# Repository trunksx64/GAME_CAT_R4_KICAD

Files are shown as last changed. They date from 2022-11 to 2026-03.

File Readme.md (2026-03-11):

# Game//Cat ::: Revisión R4 :: Versión 4.2.2

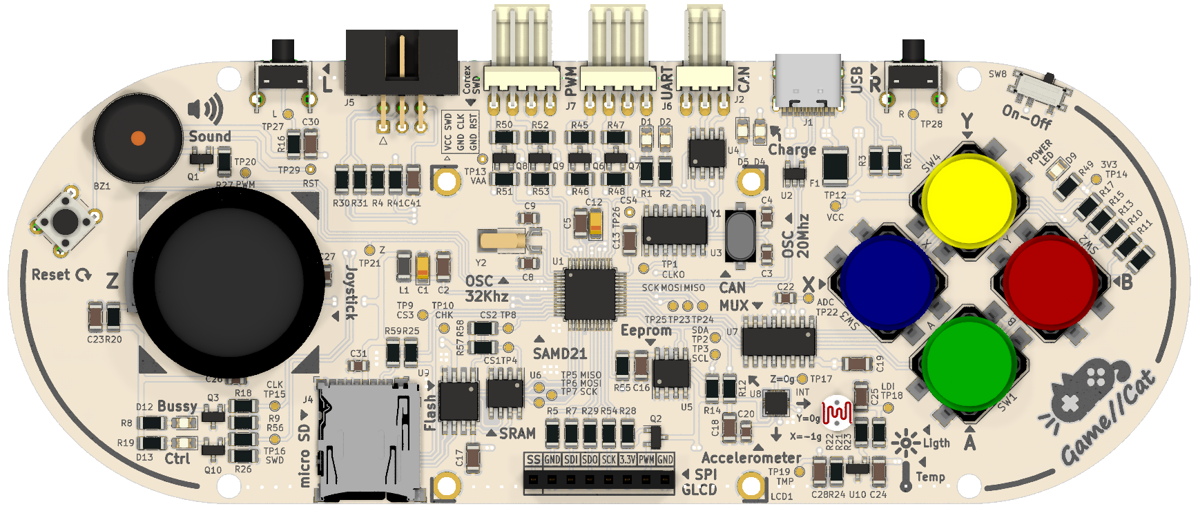
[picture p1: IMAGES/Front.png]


## Razón e Inspiración

El Game//Cat R4 es la evolución del microcontrolador de 16Bits a 32Bits, mas específicamente del PIC24H al ATSAMD21 como núcleo de control, al igual que su antecesor la idea de esta tarjeta y/ó control de desarrollo es usar dispositivos específicos para el aprendizaje, bricolaje y Hobby para proyectos abiertos o de diseño cerrado, el Hardware el Libre con la posibilidad de adaptarlo, modificarlo, cambiarlo a necesidad, claramente respetando al original. El ATSAMD21 es un microcontrolador Originalmente diseñado por ATMEL que utiliza un Nucleo ARM 0M+ dando la ventaja de ser un microcontrolador fácil de usar con Módulos flexibles y robustos, con documentación abundante tanto por lo Comunidad de ARDUINO y la empresa Microchip en este momento. Se diseñó empleando de forma similar la apariencia del Game//Cat R3, agregando mejoras y eliminando errores del anterior, por lo cual es 100% compatible a nivel de diseño.

El ATSAMD21 es compatible en este momento con Microchip Studio (Atmel Studio) y MPLABX V5.0, tanto con GCC y XC32, para programarlo se puede usar ATMEL ICE, MPLAB SNAP, PICKIT4 y El ICD4, Se planea usar el Bootloader original de ARDUINO Zero en un futuro.

Algunos Elementos "Footprints" y "Symbols" están basados en mis librerías, cuáles encontrarán en este mismo Repositorio.

## Características del Hardware

  * Microcontrolador ATSAMD21.
  * Pantalla LCD PCD8544 (Based Nokia GLCD) - SPI.
  * Joystick Análogo de 2 ejes + Botón Digital.
  * 6 Botones Digitales.
  * Accelerometro - MMA8452Q - I2C. 
  * Sensor de Temperatura (LM61).
  * Sensor de Luz (LDR).
  * Memoria Eeprom 24LCXXX - I2C.
  * Memoria Ram 23KXX - SPI.
  * Memoria Flash SST26VF032B - SPI.
  * Ranura Memoria Micro-SD - SPI.
  * Buzzer por PWM.
  * Conexión USB - Nativa por el ATSAM.
  * Conexión CAN-FD - MCP2518FD.
  * 2 LED´s de Actividad.
  * Salidas Para PWM y UART - Con figurables - 3.3V.
  * Conexión SWD Nativa para Debuger.
  * Cargador de Batería Lipo (MCP73831) con Indicador LED.
  * Regulación 3.3V mediante TPS54231.

## Características Específicas

* Para garantizar el control y tensión correspondiente para el uso de BUS CAN, se utiliza el Transeiver MCP2562FD en conjunto del CI MCP2518FD, haciendo compatible el Control con la última version del protocolo CAN.

* Para Potabilidad he agregado un control para la carga de Baterías de tipo Lipo, este gobernado él con el CI MCP73831, el cual intercambia la alimentación proveniente del conector USB y la Batería según el estado de conexión, se puede usar Baterías de 3,7V en adelante hasta un máximo de 6V, se agregó un interruptor para porder desconectar la Batería en modo portable, para evitar su descarga prologanda.

* Para el Manejo del Joystick, Botones, he empleado el CI-74HC4051, que es un Multiplexor Análogo para leer los Valores por el módulo ADC, el cual puede usarse de 10 o 12Bits en conjunto con un canal DMA si fuere necesario.

* La Comunicación por algunos de los Módulos SERCOM disponibles en los conectores Molex, posee un conversor de tensión de 3.3V a 5V de forma bidireccional con transistores Mosfet, con el fin de proteger y poder comunicar el ATSAMD21 con cualquier tipo de dispositivo.

* La Comunicación USB está dedicada por el mismo ATSAMD21, por lo que es necesario programar el Stack propio, este microcontrolador posee una enorme flexibilidad para configurar impactando de forma mínima los recursos. Es posible utilizar el Bootloader del Arduino Zero con algunas modificaciones, aún está en planes de creación, recomiendo emplear el código Generado por AMTEL START, para simplificar las configuraciones tanto de este Módulo como otros Periféricos.

* La Ranura para la Tarjeta Micro-SD, posee conexión Módulo SPI la cual esta compartida con la Memoria Ram 23Kxxx y Memoria Flash SST26VF032B, Además la pantalla posee también una conexión al segundo Módulo SPI, que puede usarse para "colgar" otros dispositivos si no vamos a usar la Pantalla.

* El control del Buzzer se ha dejado por un Pin que puede ser usado tanto por el Modulo PWM o un pin Común, su uso dependerá del Programa o Aplicación.

* Posee una Memoria I2C en conjunto con un Accelerometro, con comunicación directa.

* Los sensores de Luminosidad y Temperatura están conectados directamente a entradas Analógicas del ATSAMD21, no siendo necesario utilizar le MUX 74HC4051.

* La programación se hace por medio de la conexión ICSP o Bootloader por USB, empleando cualquier programador reciente como el ICD4, PICKIT4, SNAP o ATMEL ICE, igual estas salidas pueden usarse como cualquier puerto, teniendo presente que no poseen ninguna protección a tensiones superiores de 3,3V.

* Ya por Último, he dejado dos visualiza-dores, que usan los pines asignados para la Programación del ATSAMD21, controlados por Mosfets para no interferir con el protocolo SWD, su uso está condicionado fuera del Debug.

## Microcontrolador

  * Microcontrolador ATSAMD21 ARM 0M+ de 32Bits.
  * 256KB of flash and 32KB of SRAM.
  * Up to 48MHz operating frequency.
  * Six serial communication modules (SERCOM) configurable as UART/USART, SPI or I2C, three 16-bit timer/counters, 32-bit Real-Time Clock and calendar, 20 PWM channels, one 14-channel 12-bit ADC, one 10-bit DAC.
  * Full Speed USB Device and embedded Host.
  * 1.62V to 3.63V power supply.
  * Internal and external clock options with 48MH Digital Frequency Locked Loop (DFLL48M) and 48MHto 96MHFractional.
  * Two-pin Serial Wire Debug (SWD) programming, test and debugging interface.
  * 38 GPIO pins.
  * 10-bit, 350ksps Digital-to-Analog Converter (DAC).
  * CRC-32 generator.
  * 32-bit Real Time Counter (RTC) with clock/calendar function.
  * Generation of synchronized pulse width modulation (PWM) pattern across port pins.

## Versiones

* 2021 : 4.0.0 : Primera Versión de Diseño.
* 2021 : 4.0.1 : Mirgración completa a Kicad V6, actualización del Libreias y Logos de Diseño.
* 2021 : 4.1.0 : Cambio de Botones Pasantes a SDM.
* 2021 : 4.1.2 : Conectores Moles de tres pines a cuatro pines para Alimentación externar de dispositivos.
* 2021 : 4.1.3 : Correción y cambio de puerto de Programación SWD RJ11 a Header 2x3, similar al AVR SPI.
* 2021 : 4.1.4 : Cambio de Resistencias del conversor de nivel 5V-3.3V de 1K a 10K.
* 2022 : 4.1.5 : Se agregó Interruptor de Encendio por Batería con control Mosfet.
* 2024 : 4.1.6 : Se Elimia Resistencia de Pull para la Linea SWCLK.
* 2024 : 4.1.8 : Se Elimia Diodo del Control de Batería del control Mosfet
* 2025 : 4.2.2 : Se Corrige Mosfet de los LEDs de Estado y Conexion del BUS I2C.

## Créditos

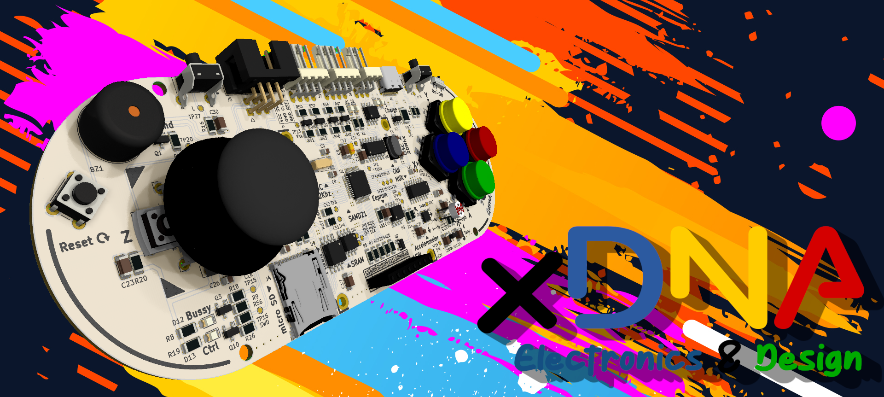
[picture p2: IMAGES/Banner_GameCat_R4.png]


xDNA Electronics & Desing es una Micro-empresa Personal, que se dedica y encarga de elaborar proyectos de Control y Automatización por pedido, su idea es colaborar y ayudar a quines a si lo requieran, el proyecto se hizo principalmente como Hobby el cual gracias a terceros se pudo implementar y hacer su creación, por lo cual se da la libertad de usarlo para experimentar sin hacer uso comercial del mismo.

## Licencia

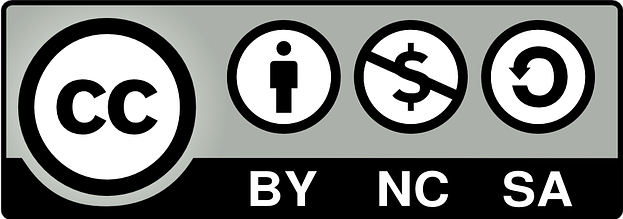
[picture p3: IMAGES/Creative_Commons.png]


Licensed under Attribution-NonCommercial-ShareAlike 4.0 International (CC BY-NC-SA 4.0)

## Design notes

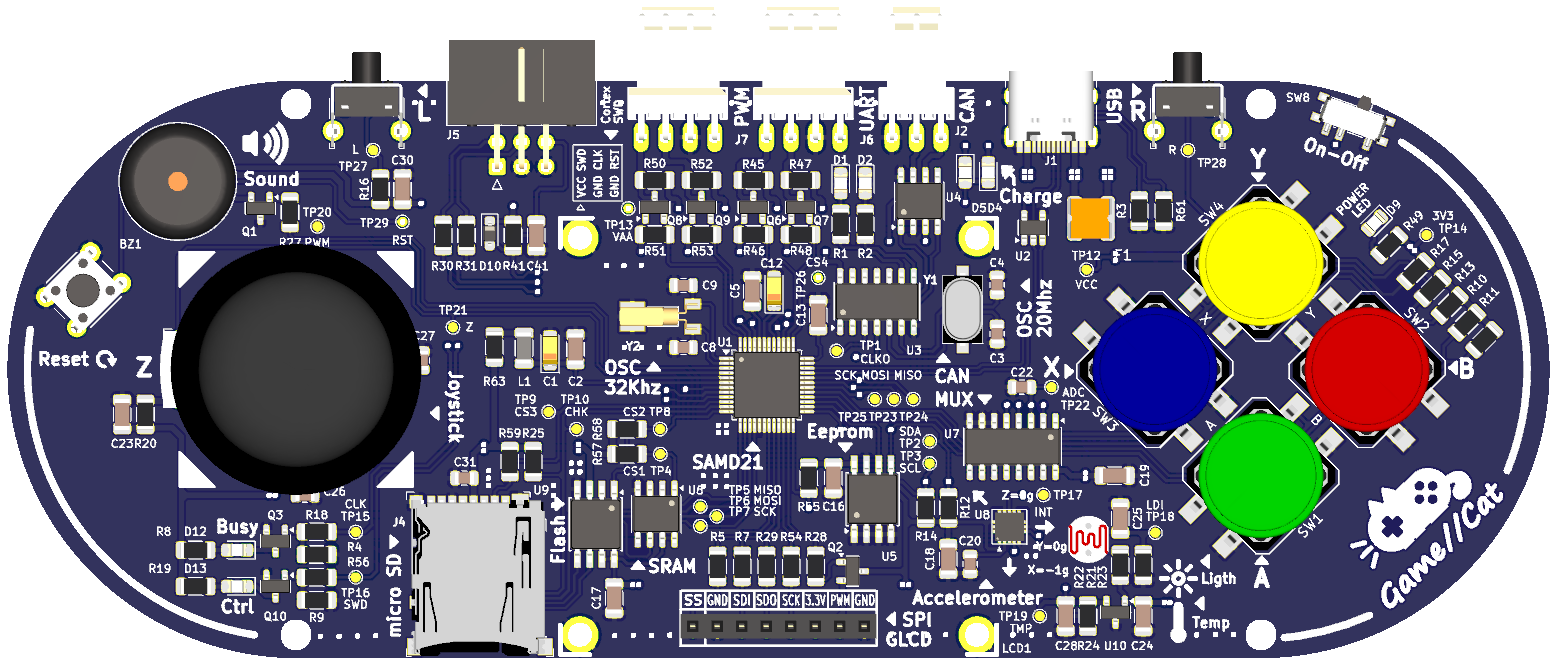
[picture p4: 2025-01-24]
Game_Cat_R4.png

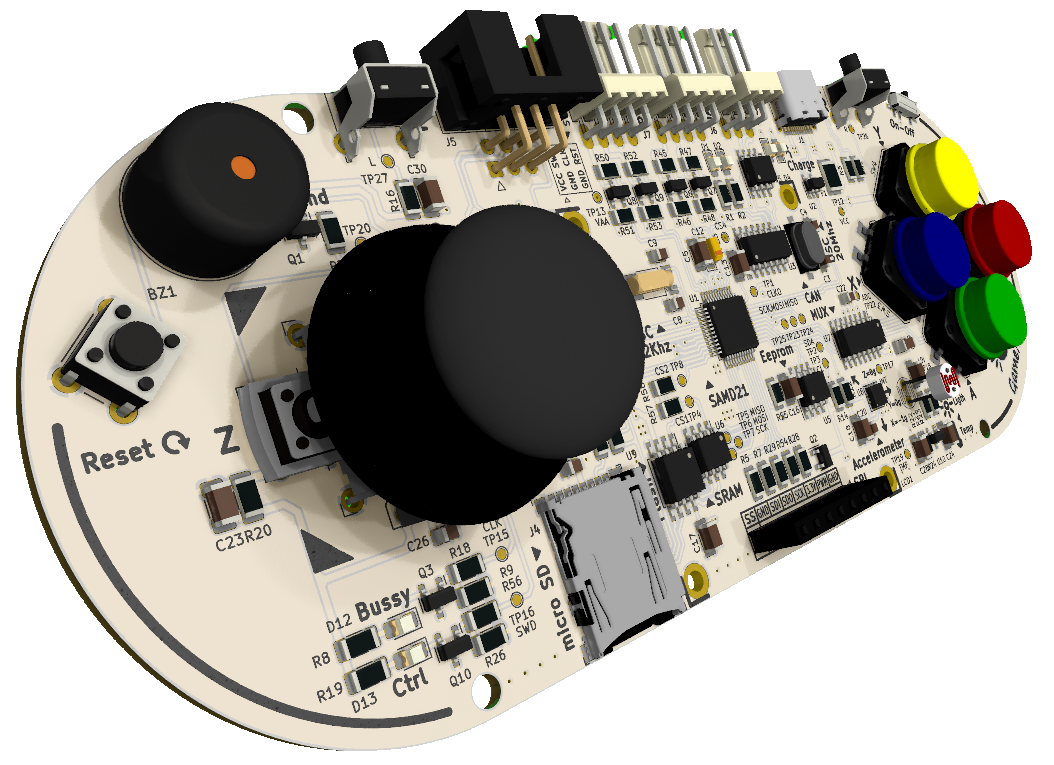
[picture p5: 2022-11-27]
IMAGES/Persp.png

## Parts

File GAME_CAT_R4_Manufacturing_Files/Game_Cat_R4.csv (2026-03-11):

# | Qty | Reference | Footprint | Value | Digikey | Datasheet
1 | 1 | BT1 | x_Connector_JST:S2B_PH_SM4_TB | 3V7 |  | ~
2 | 1 | BZ1 | Buzzer_Beeper:Buzzer_12x9.5RM7.6 | Buzzer |  | ~
3 | 1 | C1 | Capacitor_Tantalum_SMD:CP_EIA-3216-18_Kemet-A | 4.7uF | TAJA475K016RNJ | https://datasheets.kyocera-avx.com/TAJ.pdf
4 | 1 | C2 | Capacitor_SMD:C_1206_3216Metric | 100nF | C3216X7R2E104K160AE | https://product.tdk.com/system/files/dam/doc/product/capacitor/ceramic/mlcc/catalog/mlcc_commercial_soft_en.pdf
5 | 1 | C38 | Capacitor_SMD:C_1206_3216Metric | 15pF |  | ~
6 | 1 | C39 | Capacitor_Tantalum_SMD:CP_EIA-3216-18_Kemet-A | 4.7uF |  | ~
7 | 6 | C10,C23,C25,C28,C30,C41 | Capacitor_SMD:C_1206_3216Metric | 10nF |  | ~
8 | 3 | C12,C36,C45 | Capacitor_Tantalum_SMD:CP_EIA-3216-18_Kemet-A | 1uF |  | ~
9 | 4 | C20,C26,C27,C31 | Capacitor_SMD:C_0805_2012Metric | 10pF |  | ~
10 | 3 | C3,C4,C22 | Capacitor_SMD:C_0805_2012Metric | 22pF |  | ~
11 | 2 | C37,C42 | Capacitor_SMD:C_0805_2012Metric,Capacitor_SMD:C_1206_3216Metric | 47pF |  | ~
12 | 10 | C5,C11,C13,C16,C17,C18,C19,C24,C33,C40 | Capacitor_SMD:C_1206_3216Metric | 100nF |  | ~
13 | 2 | C8,C9 | Capacitor_SMD:C_0805_2012Metric | 22pF | C0805C220J5GAC7800 | https://content.kemet.com/datasheets/KEM_C1003_C0G_SMD.pdf
14 | 1 | D3 | Package_TO_SOT_SMD:SOT-23 | NUP2105L |  | http://www.onsemi.com/pub_link/Collateral/NUP2105L-D.PDF
15 | 1 | D6 | Diode_SMD:D_SOD-123 | 1N5819HW |  | ~
16 | 7 | D1,D2,D4,D5,D9,D12,D13 | LED_SMD:LED_0805_2012Metric,LED_SMD:LED_0805_2012Metric_Castellated | LED |  | ~
17 | 2 | D8,D10 | Diode_SMD:D_SOD-323_HandSoldering | BAT60J |  | ~
18 | 1 | F1 | x_Fuses:MF_SMDF200 | 500mA |  | ~
19 | 1 | J1 | x_Connector_USB:USB_C_HRO_TYPE-C-31-M-12 | USB_C |  | https://www.usb.org/sites/default/files/documents/usb_type-c.zip
20 | 1 | J2 | x_Connector_Molex:MOLEX_KK_1x03_P2.54mm_HORIZONTAL | CAN |  | ~
21 | 1 | J3 | x_Joystick:JOYSTICK_TUMB | Joystick | 09032 | https://mm.digikey.com/Volume0/opasdata/d220001/medias/docus/2339/COM-09032_Web.pdf
22 | 1 | J5 | Connector_IDC:IDC-Header_2x03_P2.54mm_Horizontal | CORTEX-SWD |  | ~
23 | 1 | J6 | x_Connector_Molex:MOLEX_KK_1x04_P2.54mm_HORIZONTAL | UART |  | ~
24 | 1 | J8 | x_Connector_Card:DM3AT_SF_PEJM5 | DM3AT-SF-PEJM5 | DM3AT-SF-PEJM5 | https://www.hirose.com/product/document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
25 | 2 | J7,TP20 | TestPoint:TestPoint_Pad_D1.0mm,x_Connector_Molex:MOLEX_KK_1x04_P2.54mm_HORIZONTAL | PWM |  | ~
26 | 1 | JP1 | Jumper:SolderJumper-2_P1.3mm_Open_RoundedPad1.0x1.5mm | Jumper CAN |  | ~
27 | 1 | L1 | Inductor_SMD:L_1206_3216Metric | FB321611T | FB321611T-260Y-S | https://calchip.com/wp-content/uploads/2023/03/fb_series.pdf
28 | 1 | L2 | Inductor_SMD:L_1206_3216Metric | BLM18PG471 |  | ~
29 | 1 | L3 | x_Inductor_SMD:L_Murata_82103C | 82103C |  | ~
30 | 1 | LCD1 | x_Display:GLCD_PCD8544_BASE | PCD8544
31 | 1 | Q4 | Package_TO_SOT_SMD:SOT-23 | FDN340P |  | ~
32 | 1 | Q5 | Package_TO_SOT_SMD:SOT-23 | NTR1P02LT1 |  | ~
33 | 2 | Q1,Q2 | Package_TO_SOT_SMD:SOT-23 | 2N2907 |  | ~
34 | 2 | Q3,Q10 | Package_TO_SOT_SMD:SOT-23 | 2N7002 |  | https://www.fairchildsemi.com/datasheets/2N/2N7002.pdf
35 | 4 | Q6,Q7,Q8,Q9 | Package_TO_SOT_SMD:SOT-23 | BS138 |  | ~
36 | 1 | R6 | Resistor_SMD:R_1206_3216Metric | 120R |  | ~
37 | 1 | R22 | x_OptoDevice:PHOTO_CELL_VT900 | R_PHOTO |  | ~
38 | 1 | R23 | Resistor_SMD:R_1206_3216Metric | 100K | RC1206FR-07100KL | https://www.yageo.com/upload/media/product/products/datasheet/rchip/PYu-RC_Group_51_RoHS_L_12.pdf
39 | 1 | R28 | Resistor_SMD:R_1206_3216Metric | 10R | RC1206FR-0710RL | https://www.yageo.com/upload/media/product/products/datasheet/rchip/PYu-RC_Group_51_RoHS_L_12.pdf
40 | 1 | R35 | Resistor_SMD:R_1206_3216Metric | 332R | RC1206FR-07332RL | https://www.yageo.com/upload/media/product/products/datasheet/rchip/PYu-RC_Group_51_RoHS_L_12.pdf
41 | 1 | R36 | Resistor_SMD:R_1206_3216Metric | 68K | RC1206FR-0768KL | https://www.yageo.com/upload/media/product/products/datasheet/rchip/PYu-RC_Group_51_RoHS_L_12.pdf
42 | 1 | R37 | Resistor_SMD:R_1206_3216Metric | 30K | RC1206FR-0730KL | https://www.yageo.com/upload/media/product/products/datasheet/rchip/PYu-RC_Group_51_RoHS_L_12.pdf
43 | 1 | R40 | Resistor_SMD:R_1206_3216Metric | 180 | RC1206JR-07180RL | https://www.yageo.com/upload/media/product/products/datasheet/rchip/PYu-RC_Group_51_RoHS_L_12.pdf
44 | 1 | R43 | Resistor_SMD:R_1206_3216Metric | 3K | RC1206FR-073KL | https://www.yageo.com/upload/media/product/products/datasheet/rchip/PYu-RC_Group_51_RoHS_L_12.pdf
45 | 1 | R55 | Resistor_SMD:R_1206_3216Metric | 4K7 | RC1206FR-074K7L | https://www.yageo.com/upload/media/product/products/datasheet/rchip/PYu-RC_Group_51_RoHS_L_12.pdf
46 | 5 | R1,R2,R8,R19,R27 | Resistor_SMD:R_1206_3216Metric | 2K2 | RC1206FR-072K2L | https://www.yageo.com/upload/media/product/products/datasheet/rchip/PYu-RC_Group_51_RoHS_L_12.pdf
47 | 2 | R18,R56 | Resistor_SMD:R_1206_3216Metric | 100R | RC1206JR-07100RL | https://www.yageo.com/upload/media/product/products/datasheet/rchip/PYu-RC_Group_51_RoHS_L_12.pdf
48 | 2 | R24,R49 | Resistor_SMD:R_1206_3216Metric | 33R | RC1206JR-0733RL | https://www.yageo.com/upload/media/product/products/datasheet/rchip/PYu-RC_Group_51_RoHS_L_12.pdf
49 | 2 | R3,R61 | Resistor_SMD:R_1206_3216Metric | 5K1 | RC1206FR-075K1L | https://www.yageo.com/upload/media/product/products/datasheet/rchip/PYu-RC_Group_51_RoHS_L_12.pdf
50 | 2 | R33,R34 | Resistor_SMD:R_1206_3216Metric | 470R | RC1206JR-07470RL | https://www.yageo.com/upload/media/product/products/datasheet/rchip/PYu-RC_Group_51_RoHS_L_12.pdf
51 | 2 | R38,R44 | Resistor_SMD:R_1206_3216Metric | 2K | RC1206FR-072KL | https://www.yageo.com/upload/media/product/products/datasheet/rchip/PYu-RC_Group_51_RoHS_L_12.pdf
52 | 27 | R4,R9,R10,R11,R12,R13,R14,R15,R16,R17,R20,R21,R25,R39,R41,R42,R45,R46,R47,R48,R50,R51,R52,R53,R57,R58,R59 | Resistor_SMD:R_1206_3216Metric | 10K | RC1206FR-0710KL | https://www.yageo.com/upload/media/product/products/datasheet/rchip/PYu-RC_Group_51_RoHS_L_12.pdf
53 | 11 | R5,R7,R29,R30,R31,R32,R54,R60,R62,R63,R64 | Resistor_SMD:R_1206_3216Metric | 0R | RC1206FR-0710KL | https://www.yageogroup.com/content/datasheet/asset/file/PYU-RC_GROUP_51_ROHS_L
54 | 1 | SW1 | x_Button_Switch_SMD:SWITCH_TACTILE_SPST_PLUNGER_CAP_GREEN_12x12mm_SMD | A
55 | 1 | SW2 | x_Button_Switch_SMD:SWITCH_TACTILE_SPST_PLUNGER_CAP_RED_12x12mm_SMD | B
56 | 1 | SW3 | x_Button_Switch_SMD:SWITCH_TACTILE_SPST_PLUNGER_CAP_BLUE_12x12mm_SMD | X
57 | 1 | SW4 | x_Button_Switch_SMD:SWITCH_TACTILE_SPST_PLUNGER_CAP_YELLOW_12x12mm_SMD | Y
58 | 1 | SW7 | Button_Switch_THT:SW_PUSH_6mm_H5mm | Reset |  | ~
59 | 1 | SW8 | Button_Switch_SMD:SW_SPDT_PCM12 | SW_SPDT |  | ~
60 | 2 | SW5,TP27 | Button_Switch_THT:SW_Tactile_SPST_Angled_PTS645Vx58-2LFS,TestPoint:TestPoint_Pad_D1.0mm | L |  | ~
61 | 2 | SW6,TP28 | Button_Switch_THT:SW_Tactile_SPST_Angled_PTS645Vx58-2LFS,TestPoint:TestPoint_Pad_D1.0mm | R |  | ~
62 | 1 | TP1 | TestPoint:TestPoint_Pad_D1.0mm | CLKO |  | ~
63 | 1 | TP2 | TestPoint:TestPoint_Pad_D1.0mm | SDA |  | ~
64 | 1 | TP3 | TestPoint:TestPoint_Pad_D1.0mm | SCL |  | ~
65 | 1 | TP4 | TestPoint:TestPoint_Pad_D1.0mm | CS1 |  | ~
66 | 1 | TP8 | TestPoint:TestPoint_Pad_D1.0mm | CS2 |  | ~
67 | 1 | TP9 | TestPoint:TestPoint_Pad_D1.0mm | CS3 |  | ~
68 | 1 | TP10 | TestPoint:TestPoint_Pad_D1.0mm | CHK |  | ~
69 | 1 | TP13 | TestPoint:TestPoint_Pad_D1.0mm | VAA |  | ~
70 | 1 | TP14 | TestPoint:TestPoint_Pad_D1.0mm | 3V3 |  | ~
71 | 1 | TP15 | TestPoint:TestPoint_Pad_D1.0mm | CLK |  | ~
72 | 1 | TP16 | TestPoint:TestPoint_Pad_D1.0mm | SWD |  | ~
73 | 1 | TP17 | TestPoint:TestPoint_Pad_D1.0mm | INT |  | ~
74 | 1 | TP18 | TestPoint:TestPoint_Pad_D1.0mm | LDI |  | ~
75 | 1 | TP19 | TestPoint:TestPoint_Pad_D1.0mm | TMP |  | ~
76 | 1 | TP21 | TestPoint:TestPoint_Pad_D1.0mm | Z |  | ~
77 | 1 | TP22 | TestPoint:TestPoint_Pad_D1.0mm | ADC |  | ~
78 | 1 | TP26 | TestPoint:TestPoint_Pad_D1.0mm | CS4 |  | ~
79 | 1 | TP29 | TestPoint:TestPoint_Pad_D1.0mm | RST |  | ~
80 | 2 | TP11,TP12 | TestPoint:TestPoint_Pad_D1.0mm | VCC |  | ~
81 | 2 | TP5,TP24 | TestPoint:TestPoint_Pad_D1.0mm | MISO |  | ~
82 | 2 | TP6,TP23 | TestPoint:TestPoint_Pad_D1.0mm | MOSI |  | ~
83 | 2 | TP7,TP25 | TestPoint:TestPoint_Pad_D1.0mm | SCK |  | ~
84 | 1 | U1 | Package_QFP:TQFP-48_7x7mm_P0.5mm | ATSAMD21G18A | ATSAMD21G18A-AU | https://ww1.microchip.com/downloads/en/DeviceDoc/SAM-D21-DA1-Family-Data-Sheet-DS40001882H.pdf
85 | 1 | U2 | Package_TO_SOT_SMD:SOT-23-5 | TPD2E2U06 |  | http://www.ti.com/lit/ds/symlink/tpd2e2u06.pdf
86 | 1 | U3 | Package_SO:SOIC-14_3.9x8.7mm_P1.27mm | MCP2518FD |  | https://ww1.microchip.com/downloads/en/DeviceDoc/20005688A.pdf
87 | 1 | U5 | Package_SO:SOIC-8_5.3x5.3mm_P1.27mm | 24CSM01 | 24CSM01T-E/ST | https://ww1.microchip.com/downloads/aemDocuments/documents/MPD/ProductDocuments/DataSheets/24CSM01-1-Mbit-3.4MHz-I2C-Serial-EEPROM-DS20006781.pdf
88 | 1 | U6 | Package_SO:SOIC-8_3.9x4.9mm_P1.27mm | 23K256 | 23K256-I/SN | https://ww1.microchip.com/downloads/en/DeviceDoc/22100F.pdf
89 | 1 | U7 | Package_SO:SOIC-16_3.9x9.9mm_P1.27mm | 74HC4051 | CD74HC4051QM96Q1 | http://www.ti.com/lit/ds/symlink/cd74hc4051.pdf
90 | 1 | U8 | x_Package_DFN_QFN:QFN_16_3x3x1mm_P0.5mm | MMA8452Q
91 | 1 | U9 | Package_SO:SOIC-8_5.3x5.3mm_P1.27mm | AT25DF641A | AT25DF641A-SH-B | https://www.renesas.com/us/en/document/dst/at25df641a-datasheet?language=en
92 | 1 | U10 | Package_TO_SOT_SMD:SOT-23 | LM61 |  | http://www.ti.com/lit/ds/symlink/lm35.pdf
93 | 1 | U11 | Package_TO_SOT_SMD:SOT-23-5 | MCP73831
94 | 1 | U12 | Package_SO:SOIC-8_3.9x4.9mm_P1.27mm | TPS54231 |  | http://www.ti.com/lit/ds/symlink/tps54233.pdf
95 | 1 | U13 | Package_SO:SOIC-8_3.9x4.9mm_P1.27mm | TCAN337GDR |  | http://www.ti.com/lit/ds/symlink/tcan337.pdf
96 | 1 | Y1 | x_Crystal:ECS_160_20_3X_TR | 20Mhz |  | ~
97 | 1 | Y2 | x_Crystal:MS1V_T1K_32.768KHZ_7PF_20PPM_TA | Crystal_GND3 | MS1V-T1K-32.768KHZ-9PF-20PPM-TA-QC | https://www.microcrystal.com/fileadmin/Media/Products/32kHz/Datasheet/MS1V-T1K.pdf

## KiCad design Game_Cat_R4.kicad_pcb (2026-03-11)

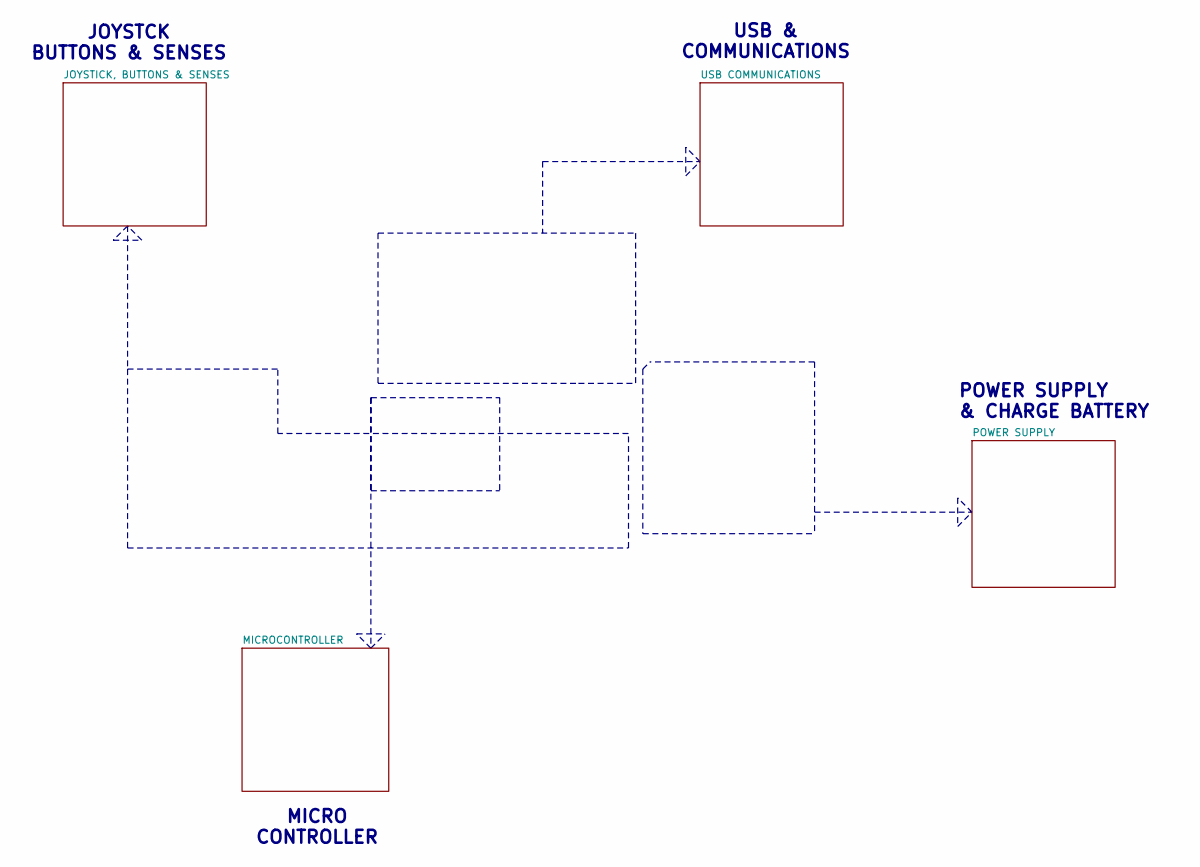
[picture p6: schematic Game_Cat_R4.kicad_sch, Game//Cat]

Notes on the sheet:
POWER SUPPLY & CHARGE BATTERY
MICRO CONTROLLER
USB & COMMUNICATIONS
JOYSTCK BUTTONS & SENSES

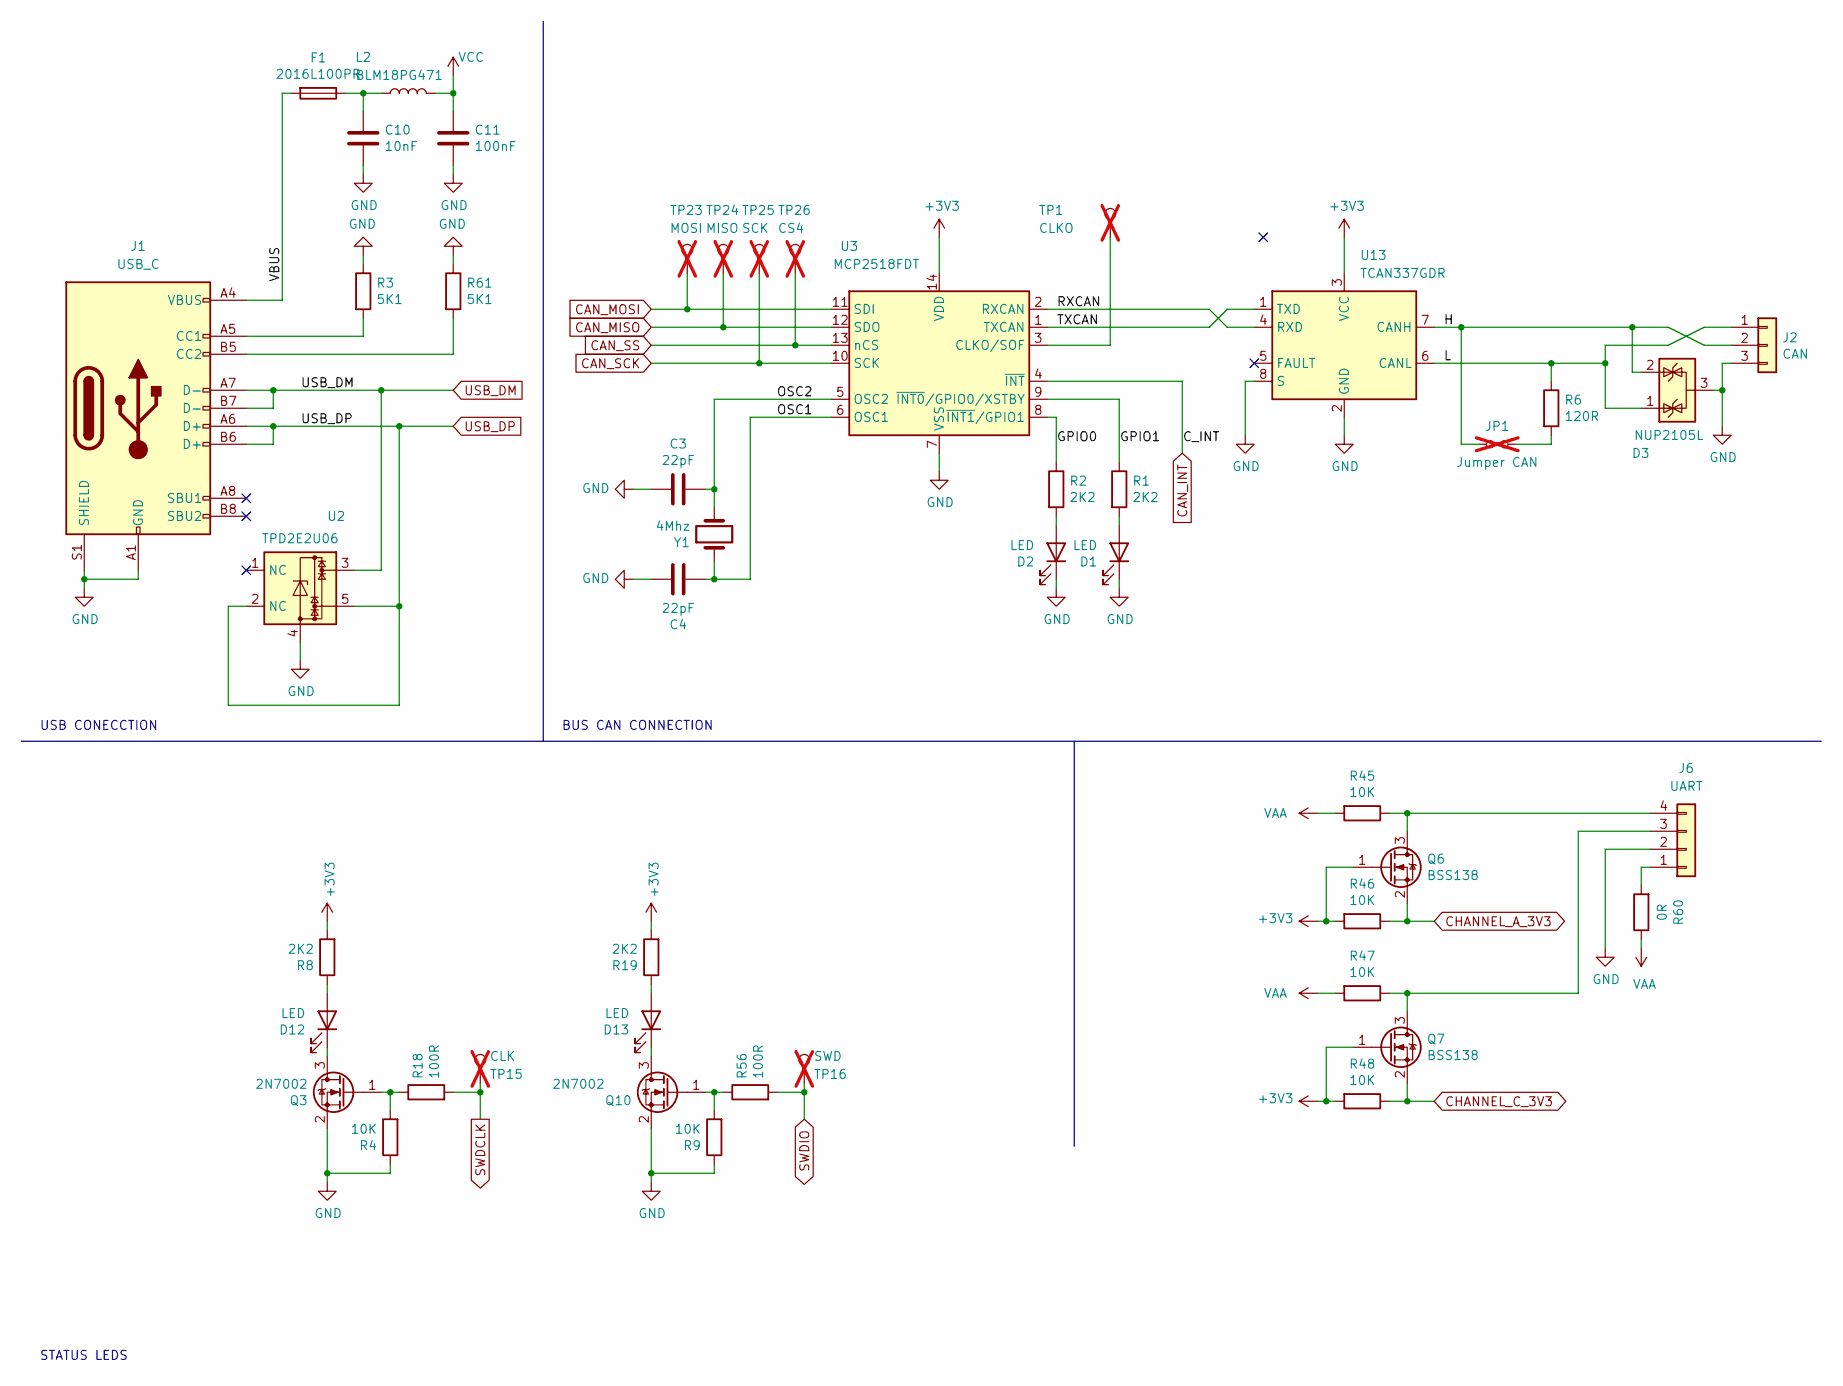
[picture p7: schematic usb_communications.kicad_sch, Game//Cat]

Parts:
C3, C4: 22pF; C_0805_2012Metric; Digikey C0805C220J5GAC7800
C10: 10nF; C_1206_3216Metric; Digikey GRM3195C1H113JA01D
C11: 100nF; C_1206_3216Metric; Digikey C3216X7R2E104K160AE
D1, D2, D12, D13: LED; LED_0805_2012Metric; Digikey LTST-C170GKT
D3: NUP2105L; SOT-23; Digikey NUP2105L
F1: 2016L100PR; MF_SMDF200; Digikey 2016L100PR
J1: USB_C; USB_C_HRO_TYPE-C-31-M-12; Digikey 12402012E212A
J2: CAN; MOLEX_KK_1x03_P2.54mm_HORIZONTAL; Digikey SWR25X-NRTC-S03-RB-BA
J6: UART; MOLEX_KK_1x04_P2.54mm_HORIZONTAL; Digikey SWR25X-NRTC-S04-RB-BA
JP1: Jumper CAN; SolderJumper-2_P1.3mm_Open_RoundedPad1.0x1.5mm; Digikey M20-9990245; not fitted
L2: BLM18PG471; L_1206_3216Metric; Digikey BLM18PG471SZ1D
Q3, Q10: 2N7002; SOT-23; Digikey 2N7002
Q6, Q7: BSS138; SOT-23; Digikey BSS138
R1, R2, R8, R19: 2K2; R_1206_3216Metric; Digikey RC1206FR-072K2L
R3, R61: 5K1; R_1206_3216Metric; Digikey RC1206FR-075K1L
R4, R9, R45, R46, R47, R48: 10K; R_1206_3216Metric; Digikey RC1206FR-0710KL
R6: 120R; R_1206_3216Metric; Digikey RC1206JR-07120RL
R18, R56: 100R; R_1206_3216Metric; Digikey RC1206JR-07100RL
R60: 0R; R_1206_3216Metric; Digikey RC1206FR-0710KL
TP1: CLKO; TestPoint_Pad_D1.0mm; not fitted
TP15: CLK; TestPoint_Pad_D1.0mm; not fitted
TP16: SWD; TestPoint_Pad_D1.0mm; not fitted
TP23: MOSI; TestPoint_Pad_D1.0mm; not fitted
TP24: MISO; TestPoint_Pad_D1.0mm; not fitted
TP25: SCK; TestPoint_Pad_D1.0mm; not fitted
TP26: CS4; TestPoint_Pad_D1.0mm; not fitted
U2: TPD2E2U06; SOT-23-5; Digikey TPD2E2U06DRLR
U3: MCP2518FDT; SOIC-14_3.9x8.7mm_P1.27mm; Digikey MCP2518FDT-H/SL
U13: TCAN337GDR; SOIC-8_3.9x4.9mm_P1.27mm; Digikey TCAN337GDR
Y1: 4Mhz; ECS_160_20_3X_TR; Digikey ECS-200-CDX-0914

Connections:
+3V3: Q6.1 (G), Q7.1 (G), R8.2, R19.2, R46.2, R48.2, U3.14 (VDD), U13.3 (VCC); also elsewhere on the board
/USB COMMUNICATIONS/GPIO0: R2.1, U3.8 (~INT1/GPIO1)
/USB COMMUNICATIONS/GPIO1: R1.1, U3.9 (~INT0/GPIO0/XSTBY)
/USB COMMUNICATIONS/H: D3.2 (K), J2.2, JP1.1, U13.7 (CANH)
/USB COMMUNICATIONS/L: D3.1 (K), J2.1, R6.1, U13.6 (CANL)
/USB COMMUNICATIONS/OSC1: C4.2, U3.6 (OSC1), Y1.1
/USB COMMUNICATIONS/OSC2: C3.2, U3.5 (OSC2), Y1.2
/USB COMMUNICATIONS/RXCAN: U3.2 (RXCAN), U13.4 (RXD)
/USB COMMUNICATIONS/TXCAN: U3.1 (TXCAN), U13.1 (TXD)
/USB COMMUNICATIONS/VBUS: F1.2, J1.A4 (VBUS), J1.A9 (VBUS), J1.B4 (VBUS), J1.B9 (VBUS)
CAN_INT: U3.4 (~INT); also elsewhere on the board
CAN_MISO: TP24.1, U3.12 (SDO); also elsewhere on the board
CAN_MOSI: TP23.1, U3.11 (SDI); also elsewhere on the board
CAN_SCK: TP25.1, U3.10 (SCK); also elsewhere on the board
CAN_SS: TP26.1, U3.13 (nCS); also elsewhere on the board
CHANNEL_A_3V3: Q6.2 (S), R46.1; also elsewhere on the board
CHANNEL_C_3V3: Q7.2 (S), R48.1; also elsewhere on the board
GND: C3.1, C4.1, C10.2, C11.2, D1.1 (K), D2.1 (K), D3.3 (A), J1.A1 (GND), J1.A12 (GND), J1.B1 (GND), J1.B12 (GND), J1.S1 (SHIELD), J2.3, J6.2, Q3.2 (S), Q10.2 (S), R3.1, R4.1, R9.1, R61.1, U2.4, U3.7 (VSS), U13.2 (GND), U13.8 (S); also elsewhere on the board
unnamed: C10.1, F1.1, L2.1
unnamed: D1.2 (A), R1.2
unnamed: D2.2 (A), R2.2
unnamed: D12.2 (A), R8.1
unnamed: D12.1 (K), Q3.3 (D)
unnamed: D13.2 (A), R19.1
unnamed: D13.1 (K), Q10.3 (D)
unnamed: J1.A5 (CC1), R3.2
unnamed: J1.B5 (CC2), R61.2
unnamed: J6.1, R60.2
unnamed: J6.3, Q7.3 (D), R47.1
unnamed: J6.4, Q6.3 (D), R45.1
unnamed: JP1.2, R6.2
unnamed: Q3.1 (G), R4.2, R18.1
unnamed: Q10.1 (G), R9.2, R56.1
unnamed: TP1.1, U3.3 (CLKO/SOF)
SWDCLK: R18.2, TP15.1; also elsewhere on the board
SWDIO: R56.2, TP16.1; also elsewhere on the board
USB_DM: J1.A7 (D-), J1.B7 (D-), U2.3; also elsewhere on the board
USB_DP: J1.A6 (D+), J1.B6 (D+), U2.2 (NC), U2.5; also elsewhere on the board
VAA: R45.2, R47.2, R60.1; also elsewhere on the board
VCC: C11.1, L2.2; also elsewhere on the board

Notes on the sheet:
BUS CAN CONNECTION
STATUS LEDS
USB CONECCTION

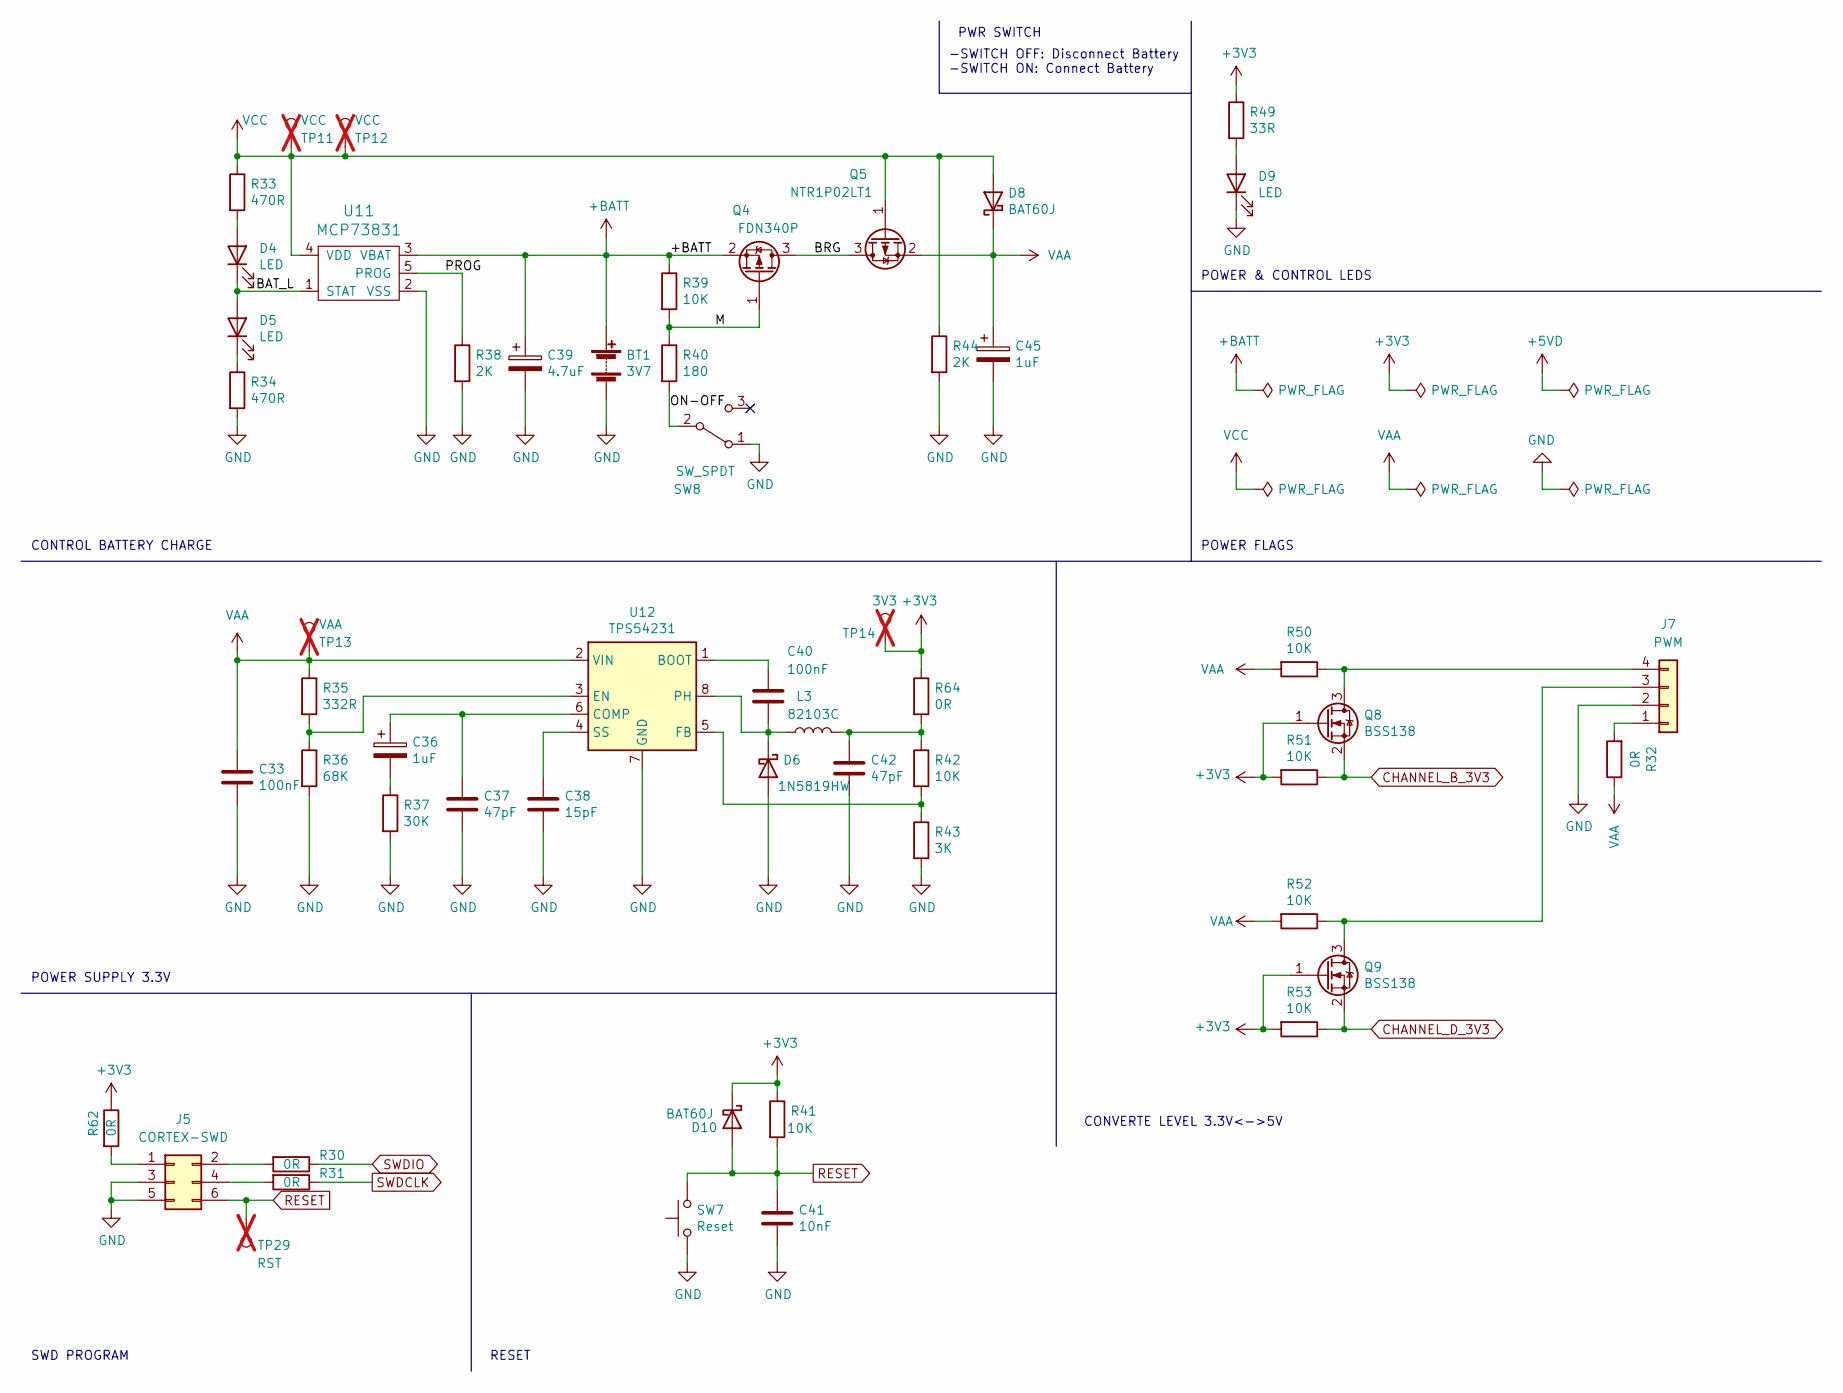
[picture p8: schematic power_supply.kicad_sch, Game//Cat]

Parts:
BT1: 3V7; S2B_PH_SM4_TB; Digikey S2B-PH-SM4-TB
C33, C40: 100nF; C_1206_3216Metric; Digikey C3216X7R2E104K160AE
C36, C45: 1uF; CP_EIA-3216-18_Kemet-A; Digikey TAJA105K016RNJ
C37: 47pF; C_0805_2012Metric; Digikey GRM21A5C2E470JW01D
C38: 15pF; C_1206_3216Metric; Digikey GCM31A5C3A150FX01D
C39: 4.7uF; CP_EIA-3216-18_Kemet-A; Digikey TAJA475K016RNJ
C41: 10nF; C_1206_3216Metric; Digikey GRM3195C1H113JA01D
C42: 47pF; C_1206_3216Metric; Digikey GCM31A5C3A470FX01D
D4, D5, D9: LED; LED_0805_2012Metric; Digikey LTST-C170GKT
D6: 1N5819HW; D_SOD-123; Digikey 1N5819HWQ-7-F
D8, D10: BAT60J; D_SOD-323_HandSoldering; Digikey BAT60JFILM
J5: CORTEX-SWD; IDC-Header_2x03_P2.54mm_Horizontal; Digikey 61200621721
J7: PWM; MOLEX_KK_1x04_P2.54mm_HORIZONTAL; Digikey SWR25X-NRTC-S04-RB-BA
L3: 82103C; L_Murata_82103C; Digikey 82103C
Q4: FDN340P; SOT-23; Digikey FDN340P
Q5: NTR1P02LT1; SOT-23; Digikey NTR1P02LT1G
Q8, Q9: BSS138; SOT-23; Digikey BSS138
R30, R31, R32, R62, R64: 0R; R_1206_3216Metric; Digikey RC1206FR-0710KL
R33, R34: 470R; R_1206_3216Metric; Digikey RC1206JR-07470RL
R35: 332R; R_1206_3216Metric; Digikey RC1206FR-07332RL
R36: 68K; R_1206_3216Metric; Digikey RC1206FR-0768KL
R37: 30K; R_1206_3216Metric; Digikey RC1206FR-0730KL
R38, R44: 2K; R_1206_3216Metric; Digikey RC1206FR-072KL
R39, R41, R42, R50, R51, R52, R53: 10K; R_1206_3216Metric; Digikey RC1206FR-0710KL
R40: 180; R_1206_3216Metric; Digikey RC1206JR-07180RL
R43: 3K; R_1206_3216Metric; Digikey RC1206FR-073KL
R49: 33R; R_1206_3216Metric; Digikey RC1206JR-0733RL
SW7: Reset; SW_PUSH_6mm_H5mm; Digikey PTS645SK50SMTR92 LFS
SW8: SW_SPDT; SW_SPDT_PCM12; Digikey PCM12SMTR
TP11, TP12: VCC; TestPoint_Pad_D1.0mm; not fitted
TP13: VAA; TestPoint_Pad_D1.0mm; not fitted
TP14: 3V3; TestPoint_Pad_D1.0mm; not fitted
TP29: RST; TestPoint_Pad_D1.0mm; not fitted
U11: MCP73831; SOT-23-5; Digikey MCP73831T-5ACI/OT
U12: TPS54231; SOIC-8_3.9x4.9mm_P1.27mm; Digikey TPS54231D

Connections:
+3V3: D10.1 (K), Q8.1 (G), Q9.1 (G), R41.1, R49.1, R51.2, R53.2, R62.1, R64.1, TP14.1; also elsewhere on the board
+BATT: BT1.1 (+), C39.1, Q4.2 (S), R39.1, U11.3 (VBAT)
/POWER SUPPLY/BAT_L: D4.1 (K), D5.2 (A), U11.1 (STAT)
/POWER SUPPLY/BRG: Q4.3 (D), Q5.3 (D); also elsewhere on the board
/POWER SUPPLY/M: Q4.1 (G), R39.2, R40.1; also elsewhere on the board
/POWER SUPPLY/ON-OFF: R40.2, SW8.2 (B)
/POWER SUPPLY/PROG: R38.1, U11.5 (PROG)
CHANNEL_B_3V3: Q8.2 (S), R51.1; also elsewhere on the board
CHANNEL_D_3V3: Q9.2 (S), R53.1; also elsewhere on the board
GND: BT1.2 (-), C33.2, C37.2, C38.2, C39.2, C41.2, C42.2, C45.2, D6.2 (A), D9.1 (K), J5.3, J5.5, J7.2, R34.2, R36.2, R37.2, R38.2, R43.2, R44.2, SW7.1, SW8.1 (A), U11.2 (VSS), U12.7 (GND); also elsewhere on the board
unnamed: C36.2, R37.1
unnamed: C42.1, L3.2, R42.1, R64.2
unnamed: D4.2 (A), R33.2
unnamed: D5.1 (K), R34.1
unnamed: C40.2, D6.1 (K), L3.1, U12.8 (PH)
unnamed: D9.2 (A), R49.2
unnamed: J5.1, R62.2
unnamed: J5.2, R30.2
unnamed: J5.4, R31.2
unnamed: J7.1, R32.2
unnamed: J7.3, Q9.3 (D), R52.1
unnamed: J7.4, Q8.3 (D), R50.1
unnamed: C40.1, U12.1 (BOOT)
unnamed: C36.1, C37.1, U12.6 (COMP)
unnamed: R35.2, R36.1, U12.3 (EN)
unnamed: R42.2, R43.1, U12.5 (FB)
unnamed: C38.1, U12.4 (SS)
RESET: C41.1, D10.2 (A), J5.6, R41.2, SW7.2, TP29.1; also elsewhere on the board
SWDCLK: R31.1; also elsewhere on the board
SWDIO: R30.1; also elsewhere on the board
VAA: C33.1, C45.1, D8.1 (K), Q5.2 (S), R32.1, R35.1, R50.2, R52.2, TP13.1, U12.2 (VIN); also elsewhere on the board
VCC: D8.2 (A), Q5.1 (G), R33.1, R44.1, TP11.1, TP12.1, U11.4 (VDD); also elsewhere on the board

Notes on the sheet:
CONTROL BATTERY CHARGE
PWR SWITCH
POWER SUPPLY 3.3V
CONVERTE LEVEL 3.3V<->5V
POWER FLAGS
-SWITCH OFF: Disconnect Battery -SWITCH ON: Connect Battery
POWER & CONTROL LEDS
RESET
SWD PROGRAM

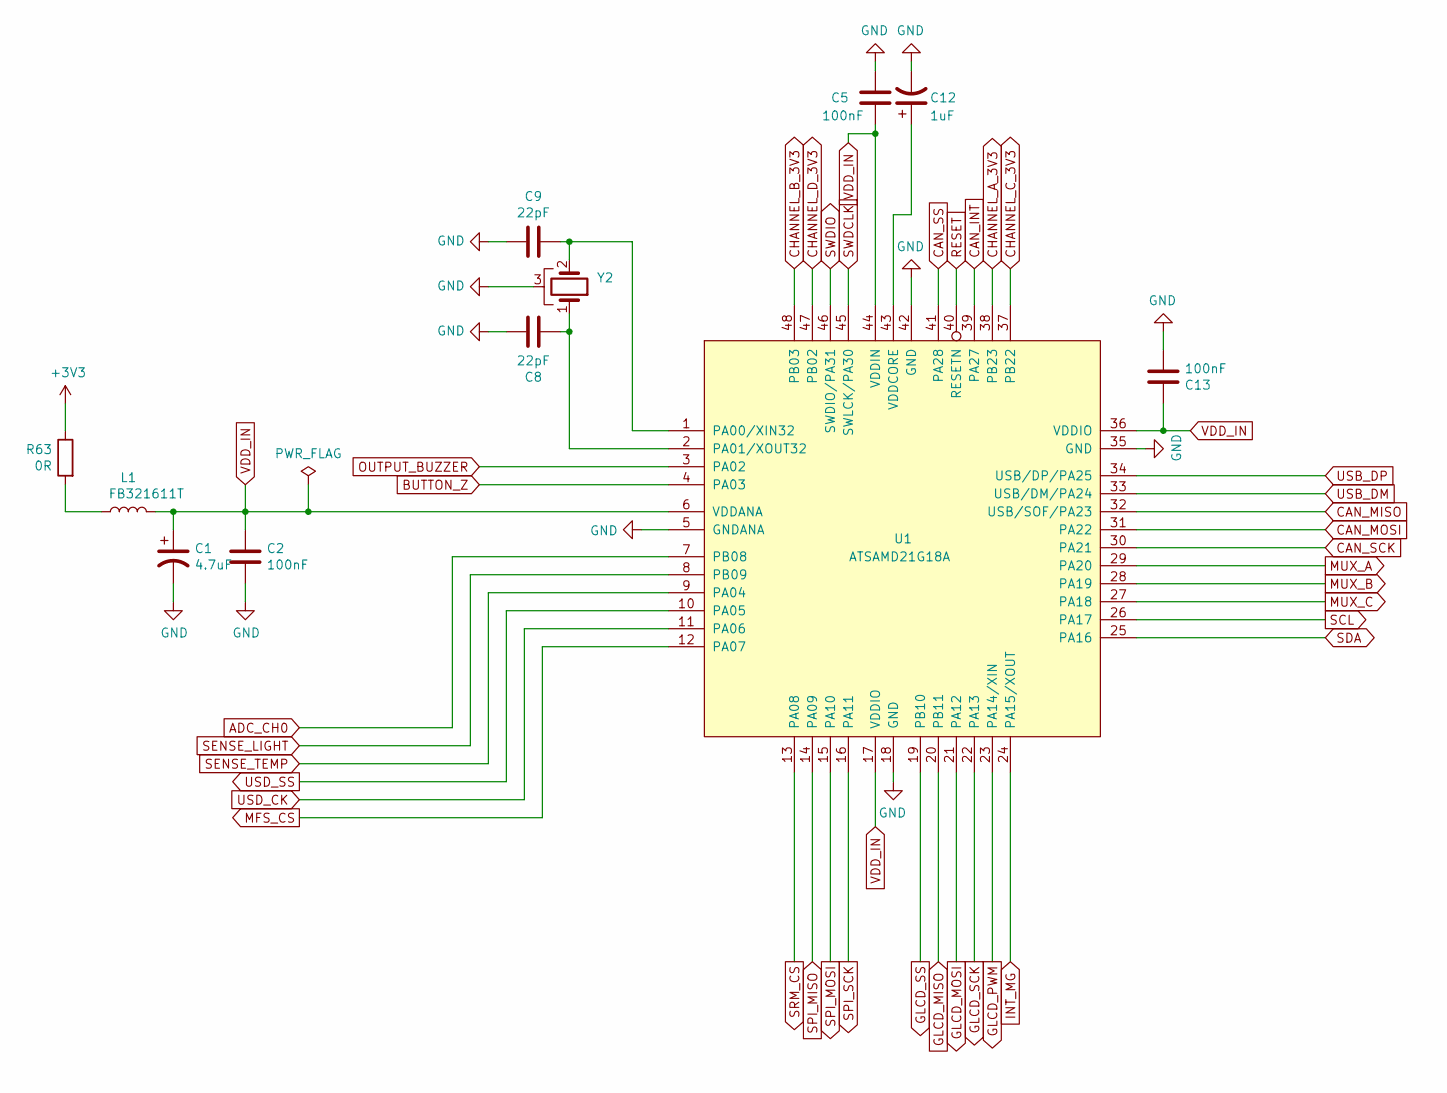
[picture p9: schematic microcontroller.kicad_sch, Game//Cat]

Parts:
C1: 4.7uF; CP_EIA-3216-18_Kemet-A; Digikey TAJA475K016RNJ
C2, C5, C13: 100nF; C_1206_3216Metric; Digikey C3216X7R2E104K160AE
C8, C9: 22pF; C_0805_2012Metric; Digikey C0805C220J5GAC7800
C12: 1uF; CP_EIA-3216-18_Kemet-A; Digikey TAJA105K016RNJ
L1: FB321611T; L_1206_3216Metric; Digikey FB321611T-260Y-S
R63: 0R; R_1206_3216Metric; Digikey RC1206FR-0710KL
U1: ATSAMD21G18A; TQFP-48_7x7mm_P0.5mm; Digikey ATSAMD21G18A-AU
Y2: Crystal_GND3; MS1V_T1K_32.768KHZ_7PF_20PPM_TA; Digikey MS1V-T1K-32.768KHZ-9PF-20PPM-TA-QC

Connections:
+3V3: R63.1; also elsewhere on the board
ADC_CH0: U1.7 (PB08); also elsewhere on the board
BUTTON_Z: U1.4 (PA03); also elsewhere on the board
CAN_INT: U1.39 (PA27); also elsewhere on the board
CAN_MISO: U1.32 (USB/SOF/PA23); also elsewhere on the board
CAN_MOSI: U1.31 (PA22); also elsewhere on the board
CAN_SCK: U1.30 (PA21); also elsewhere on the board
CAN_SS: U1.41 (PA28); also elsewhere on the board
CHANNEL_A_3V3: U1.38 (PB23); also elsewhere on the board
CHANNEL_B_3V3: U1.48 (PB03); also elsewhere on the board
CHANNEL_C_3V3: U1.37 (PB22); also elsewhere on the board
CHANNEL_D_3V3: U1.47 (PB02); also elsewhere on the board
GLCD_MISO: U1.20 (PB11); also elsewhere on the board
GLCD_MOSI: U1.21 (PA12); also elsewhere on the board
GLCD_PWM: U1.23 (PA14/XIN); also elsewhere on the board
GLCD_SCK: U1.22 (PA13); also elsewhere on the board
GLCD_SS: U1.19 (PB10); also elsewhere on the board
GND: C1.2, C2.2, C5.2, C8.1, C9.1, C12.2, C13.2, U1.5 (GNDANA), U1.18 (GND), U1.35 (GND), U1.42 (GND), Y2.3; also elsewhere on the board
INT_MG: U1.24 (PA15/XOUT); also elsewhere on the board
MFS_CS: U1.12 (PA07); also elsewhere on the board
MUX_A: U1.29 (PA20); also elsewhere on the board
MUX_B: U1.28 (PA19); also elsewhere on the board
MUX_C: U1.27 (PA18); also elsewhere on the board
unnamed: L1.1, R63.2
unnamed: C9.2, U1.1 (PA00/XIN32), Y2.2
unnamed: C8.2, U1.2 (PA01/XOUT32), Y2.1
unnamed: C12.1, U1.43 (VDDCORE)
OUTPUT_BUZZER: U1.3 (PA02); also elsewhere on the board
RESET: U1.40 (RESETN); also elsewhere on the board
SCL: U1.26 (PA17); also elsewhere on the board
SDA: U1.25 (PA16); also elsewhere on the board
SENSE_LIGHT: U1.8 (PB09); also elsewhere on the board
SENSE_TEMP: U1.9 (PA04); also elsewhere on the board
SPI_MISO: U1.14 (PA09); also elsewhere on the board
SPI_MOSI: U1.15 (PA10); also elsewhere on the board
SPI_SCK: U1.16 (PA11); also elsewhere on the board
SRM_CS: U1.13 (PA08); also elsewhere on the board
SWDCLK: U1.45 (SWLCK/PA30); also elsewhere on the board
SWDIO: U1.46 (SWDIO/PA31); also elsewhere on the board
USB_DM: U1.33 (USB/DM/PA24); also elsewhere on the board
USB_DP: U1.34 (USB/DP/PA25); also elsewhere on the board
USD_CK: U1.11 (PA06); also elsewhere on the board
USD_SS: U1.10 (PA05); also elsewhere on the board
VDD_IN: C1.1, C2.1, C5.1, C13.1, L1.2, U1.6 (VDDANA), U1.17 (VDDIO), U1.36 (VDDIO), U1.44 (VDDIN)

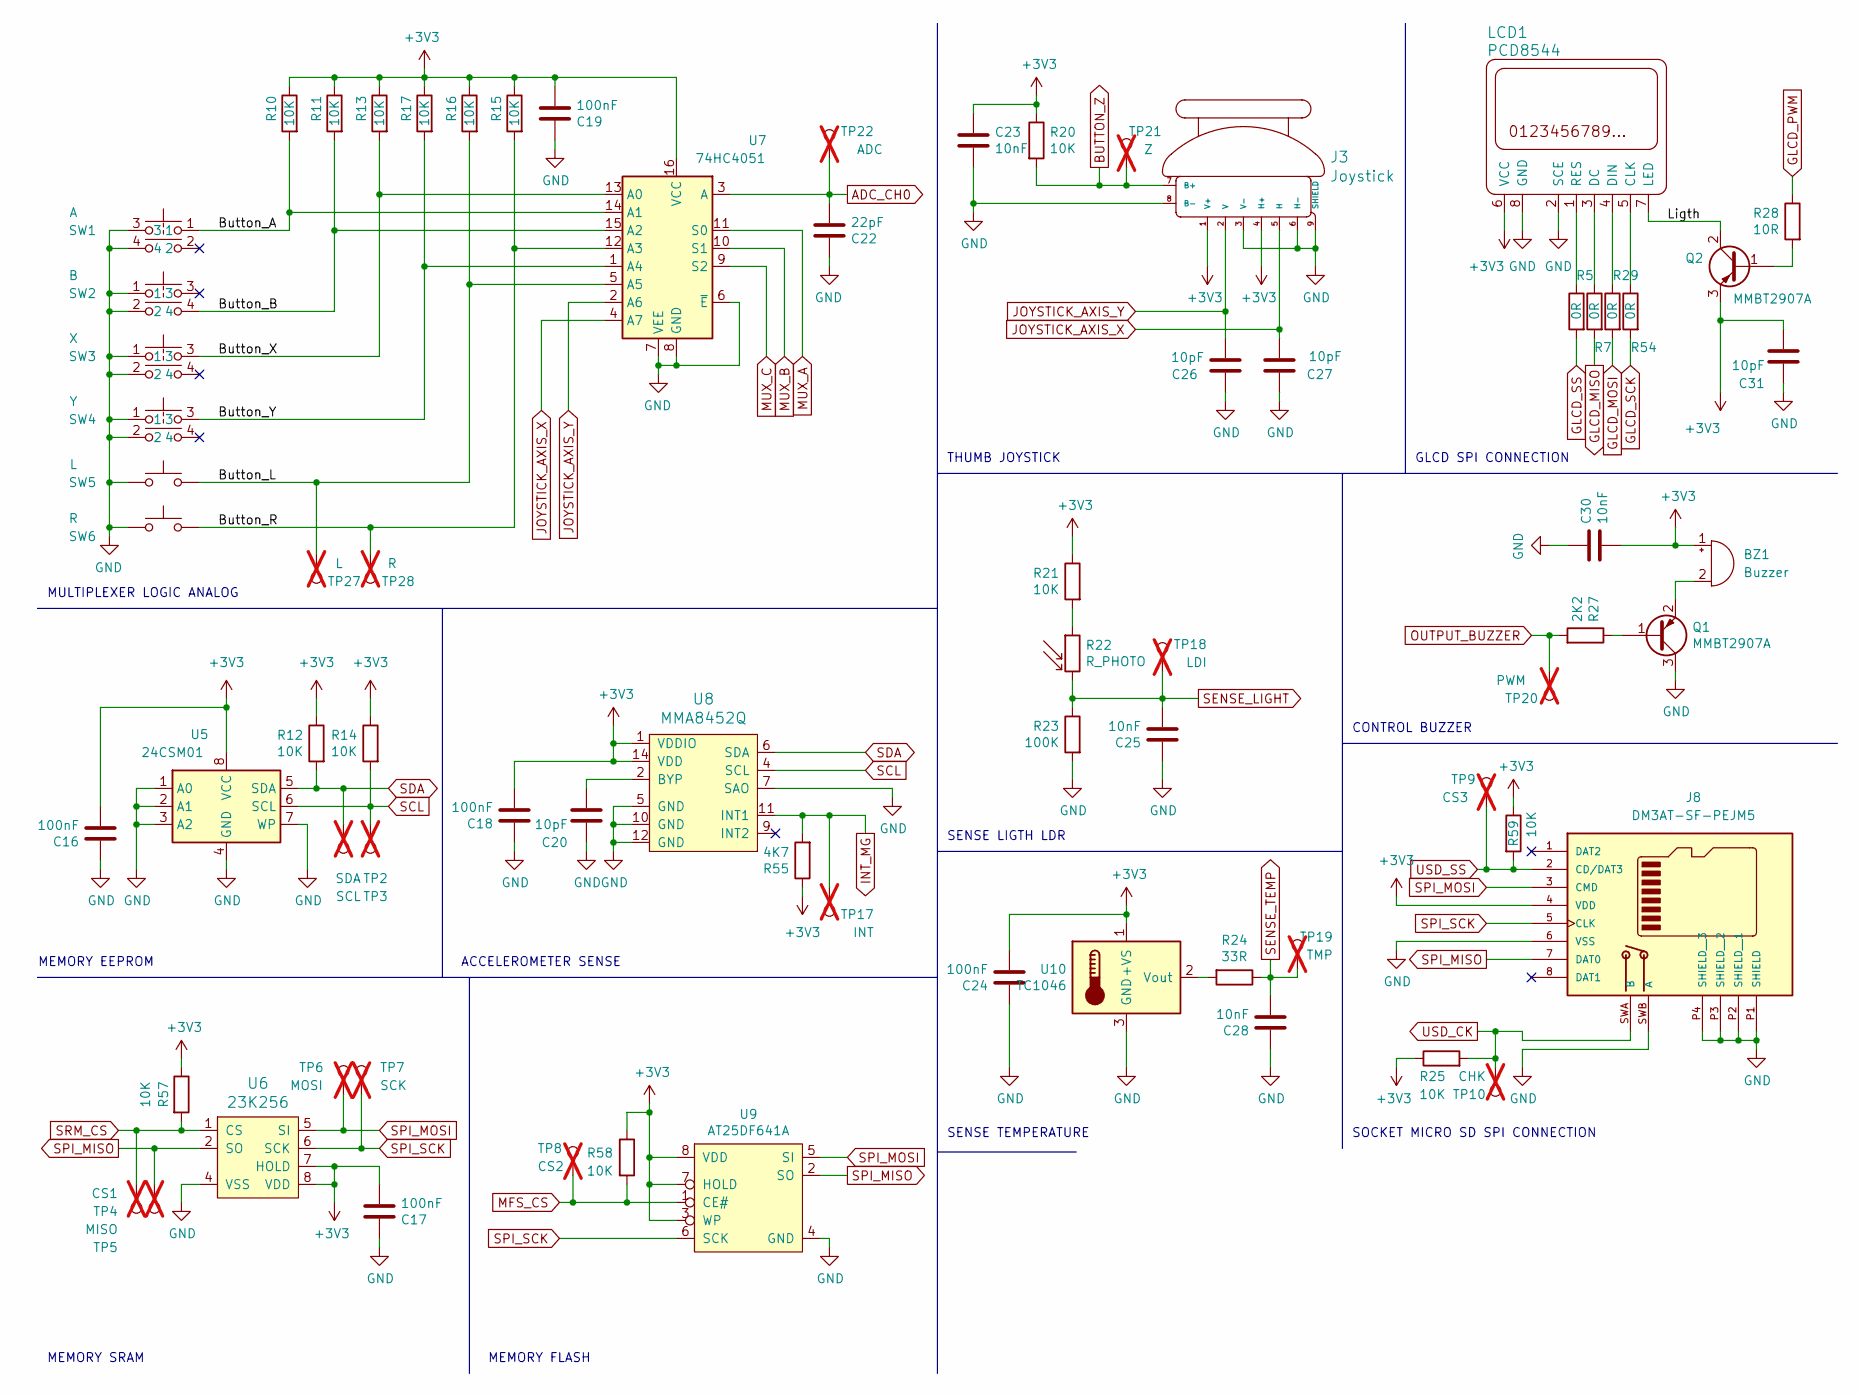
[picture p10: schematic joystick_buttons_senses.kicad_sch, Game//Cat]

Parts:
BZ1: Buzzer; AT_1224_TWT_5V_2_R; Digikey AI-1223-TWT-3V-2-R
C16, C17, C18, C19, C24: 100nF; C_1206_3216Metric; Digikey C3216X7R2E104K160AE
C20, C26, C27, C31: 10pF; C_0805_2012Metric; Digikey GRM21A5C2E100JW01D
C22: 22pF; C_0805_2012Metric; Digikey C0805C220J5GAC7800
C23, C25, C28, C30: 10nF; C_1206_3216Metric; Digikey GRM3195C1H113JA01D
J3: Joystick; JOYSTICK_TUMB; Digikey 09032
J8: DM3AT-SF-PEJM5; DM3AT_SF_PEJM5; Digikey DM3AT-SF-PEJM5
LCD1: PCD8544; GLCD_PCD8544_BASE; Digikey SSW-108-01-F-S
Q1, Q2: MMBT2907A; SOT-23; Digikey MMBT2907A-7-F
R5, R7, R29, R54: 0R; R_1206_3216Metric; Digikey RC1206FR-0710KL
R10, R11, R12, R13, R14, R15, R16, R17, R20, R21, R25, R57, R58, R59: 10K; R_1206_3216Metric; Digikey RC1206FR-0710KL
R22: R_PHOTO; PHOTO_CELL_VT900; Digikey N5AC501085
R23: 100K; R_1206_3216Metric; Digikey RC1206FR-07100KL
R24: 33R; R_1206_3216Metric; Digikey RC1206JR-0733RL
R27: 2K2; R_1206_3216Metric; Digikey RC1206FR-072K2L
R28: 10R; R_1206_3216Metric; Digikey RC1206FR-0710RL
R55: 4K7; R_1206_3216Metric; Digikey RC1206FR-074K7L
SW1: A; SWITCH_TACTILE_SPST_PLUNGER_CAP_GREEN_12x12mm_SMD; Digikey TL3300AF160Q
SW2: B; SWITCH_TACTILE_SPST_PLUNGER_CAP_RED_12x12mm_SMD; Digikey TL3300AF160Q
SW3: X; SWITCH_TACTILE_SPST_PLUNGER_CAP_BLUE_12x12mm_SMD; Digikey TL3300AF160Q
SW4: Y; SWITCH_TACTILE_SPST_PLUNGER_CAP_YELLOW_12x12mm_SMD; Digikey TL3300AF160Q
SW5: L; SW_Tactile_SPST_Angled_PTS645Vx58-2LFS; Digikey CT1102V3.85F160
SW6: R; SW_Tactile_SPST_Angled_PTS645Vx58-2LFS; Digikey CT1102V3.85F160
TP2: SDA; TestPoint_Pad_D1.0mm; not fitted
TP3: SCL; TestPoint_Pad_D1.0mm; not fitted
TP4: CS1; TestPoint_Pad_D1.0mm; not fitted
TP5: MISO; TestPoint_Pad_D1.0mm; not fitted
TP6: MOSI; TestPoint_Pad_D1.0mm; not fitted
TP7: SCK; TestPoint_Pad_D1.0mm; not fitted
TP8: CS2; TestPoint_Pad_D1.0mm; not fitted
TP9: CS3; TestPoint_Pad_D1.0mm; not fitted
TP10: CHK; TestPoint_Pad_D1.0mm; not fitted
TP17: INT; TestPoint_Pad_D1.0mm; not fitted
TP18: LDI; TestPoint_Pad_D1.0mm; not fitted
TP19: TMP; TestPoint_Pad_D1.0mm; not fitted
TP20: PWM; TestPoint_Pad_D1.0mm; not fitted
TP21: Z; TestPoint_Pad_D1.0mm; not fitted
TP22: ADC; TestPoint_Pad_D1.0mm; not fitted
TP27: L; TestPoint_Pad_D1.0mm; not fitted
TP28: R; TestPoint_Pad_D1.0mm; not fitted
U5: 24CSM01; SOIC-8_5.3x5.3mm_P1.27mm; Digikey 24CSM01T-E/ST
U6: 23K256; SOIC-8_3.9x4.9mm_P1.27mm; Digikey 23K256-I/SN
U7: 74HC4051; SOIC-16_3.9x9.9mm_P1.27mm; Digikey CD74HC4051QM96Q1
U8: MMA8452Q; QFN_16_3x3x1mm_P0.5mm; Digikey MMA8452QT
U9: AT25DF641A; SOIC-8_5.3x5.3mm_P1.27mm; Digikey AT25DF641A-SH-B
U10: TC1046; SOT-23; Digikey TC1046VNBTR

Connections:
+3V3: BZ1.1 (-), C16.2, C17.2, C18.2, C19.2, C23.1, C24.2, C30.2, C31.2, J3.1 (V+), J3.4 (H+~), J8.4 (VDD), LCD1.6 (VCC), Q2.3 (E), R10.1, R11.1, R12.1, R13.1, R14.1, R15.1, R16.1, R17.1, R20.1, R21.1, R25.1, R55.1, R57.1, R58.1, R59.1, U5.8 (VCC), U6.7 (HOLD), U6.8 (VDD), U7.16 (VCC), U8.1 (VDDIO), U8.14 (VDD), U9.3 (WP), U9.7 (HOLD), U9.8 (VDD), U10.1 (+VS); also elsewhere on the board
/JOYSTICK, BUTTONS & SENSES/Button_A: R10.2, SW1.1, U7.14 (A1)
/JOYSTICK, BUTTONS & SENSES/Button_B: R11.2, SW2.4, U7.15 (A2)
/JOYSTICK, BUTTONS & SENSES/Button_L: R16.2, SW5.2, TP27.1, U7.5 (A5)
/JOYSTICK, BUTTONS & SENSES/Button_R: R15.2, SW6.1, TP28.1, U7.12 (A3)
/JOYSTICK, BUTTONS & SENSES/Button_X: R13.2, SW3.3, U7.13 (A0)
/JOYSTICK, BUTTONS & SENSES/Button_Y: R17.2, SW4.3, U7.1 (A4)
/JOYSTICK, BUTTONS & SENSES/Ligth: LCD1.7 (LED), Q2.2 (C)
ADC_CH0: C22.2, TP22.1, U7.3 (A); also elsewhere on the board
BUTTON_Z: J3.7 (B+), R20.2, TP21.1; also elsewhere on the board
GLCD_MISO: R7.2; also elsewhere on the board
GLCD_MOSI: R29.2; also elsewhere on the board
GLCD_PWM: R28.1; also elsewhere on the board
GLCD_SCK: R54.2; also elsewhere on the board
GLCD_SS: R5.2; also elsewhere on the board
GND: C16.1, C17.1, C18.1, C19.1, C20.1, C22.1, C23.2, C24.1, C25.1, C26.1, C27.1, C28.1, C30.1, C31.1, J3.3 (V-), J3.6 (H-), J3.8 (B-), J3.9 (SHIELD), J8.6 (VSS), J8.P1 (SHIELD), J8.P2 (SHIELD__1), J8.P3 (SHIELD__2), J8.P4 (SHIELD__3), J8.SWB (A), LCD1.2 (SCE), LCD1.8 (GND), Q1.3 (C), R23.2, SW1.3, SW1.4, SW2.1, SW2.2, SW3.1, SW3.2, SW4.1, SW4.2, SW5.1, SW6.2, U5.1 (A0), U5.2 (A1), U5.3 (A2), U5.4 (GND), U5.7 (WP), U6.4 (VSS), U7.6 (~E), U7.7 (VEE), U7.8 (GND), U8.5 (GND), U8.7 (SAO), U8.10 (GND), U8.12 (GND), U9.4 (GND), U10.3 (GND); also elsewhere on the board
INT_MG: R55.2, TP17.1, U8.11 (INT1); also elsewhere on the board
JOYSTICK_AXIS_X: C27.2, J3.5 (H), U7.4 (A7)
JOYSTICK_AXIS_Y: C26.2, J3.2 (V), U7.2 (A6)
MFS_CS: R58.2, TP8.1, U9.1 (CE#); also elsewhere on the board
MUX_A: U7.11 (S0); also elsewhere on the board
MUX_B: U7.10 (S1); also elsewhere on the board
MUX_C: U7.9 (S2); also elsewhere on the board
unnamed: BZ1.2 (+), Q1.2 (E)
unnamed: LCD1.5 (CLK), R54.1
unnamed: LCD1.3 (DC), R7.1
unnamed: LCD1.4 (DIN), R29.1
unnamed: LCD1.1 (RES), R5.1
unnamed: Q1.1 (B), R27.1
unnamed: Q2.1 (B), R28.2
unnamed: R21.2, R22.1
unnamed: C20.2, U8.2 (BYP)
unnamed: R24.2, U10.2 (Vout)
OUTPUT_BUZZER: R27.2, TP20.1; also elsewhere on the board
SCL: R14.2, TP3.1, U5.6 (SCL), U8.4 (SCL); also elsewhere on the board
SDA: R12.2, TP2.1, U5.5 (SDA), U8.6 (SDA); also elsewhere on the board
SENSE_LIGHT: C25.2, R22.2, R23.1, TP18.1; also elsewhere on the board
SENSE_TEMP: C28.2, R24.1, TP19.1; also elsewhere on the board
SPI_MISO: J8.7 (DAT0), TP5.1, U6.2 (SO), U9.2 (SO); also elsewhere on the board
SPI_MOSI: J8.3 (CMD), TP6.1, U6.5 (SI), U9.5 (SI); also elsewhere on the board
SPI_SCK: J8.5 (CLK), TP7.1, U6.6 (SCK), U9.6 (SCK); also elsewhere on the board
SRM_CS: R57.2, TP4.1, U6.1 (CS); also elsewhere on the board
USD_CK: J8.SWA (B), R25.2, TP10.1; also elsewhere on the board
USD_SS: J8.2 (CD/DAT3), R59.2, TP9.1; also elsewhere on the board

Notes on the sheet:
MULTIPLEXER LOGIC ANALOG
MEMORY EEPROM
ACCELEROMETER SENSE
MEMORY SRAM
SOCKET MICRO SD SPI CONNECTION
SENSE TEMPERATURE
CONTROL BUZZER
THUMB JOYSTICK
MEMORY FLASH
SENSE LIGTH LDR
GLCD SPI CONNECTION

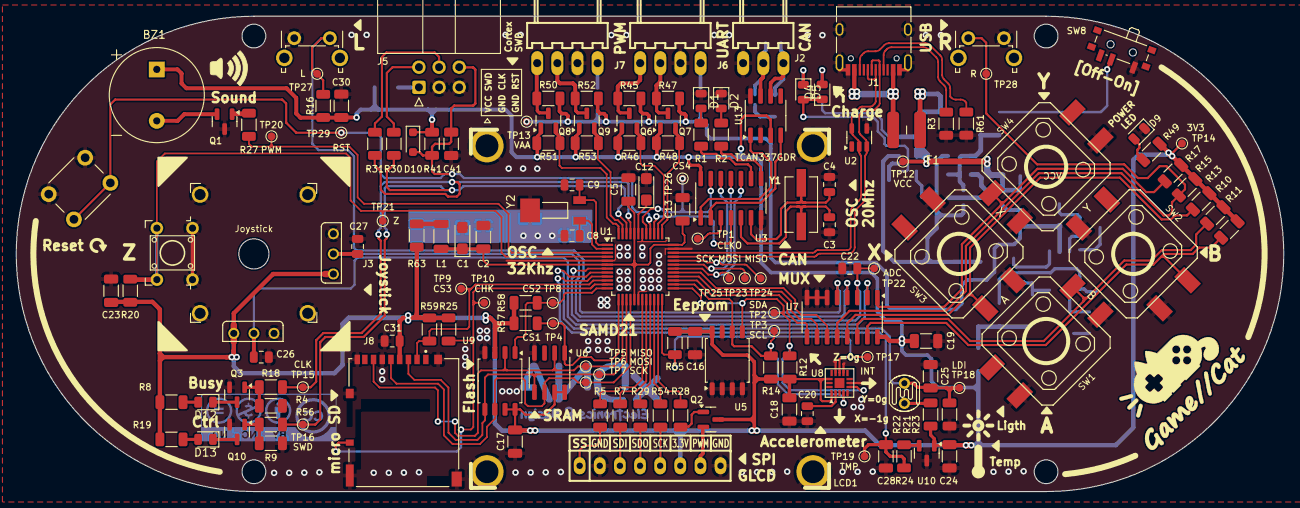
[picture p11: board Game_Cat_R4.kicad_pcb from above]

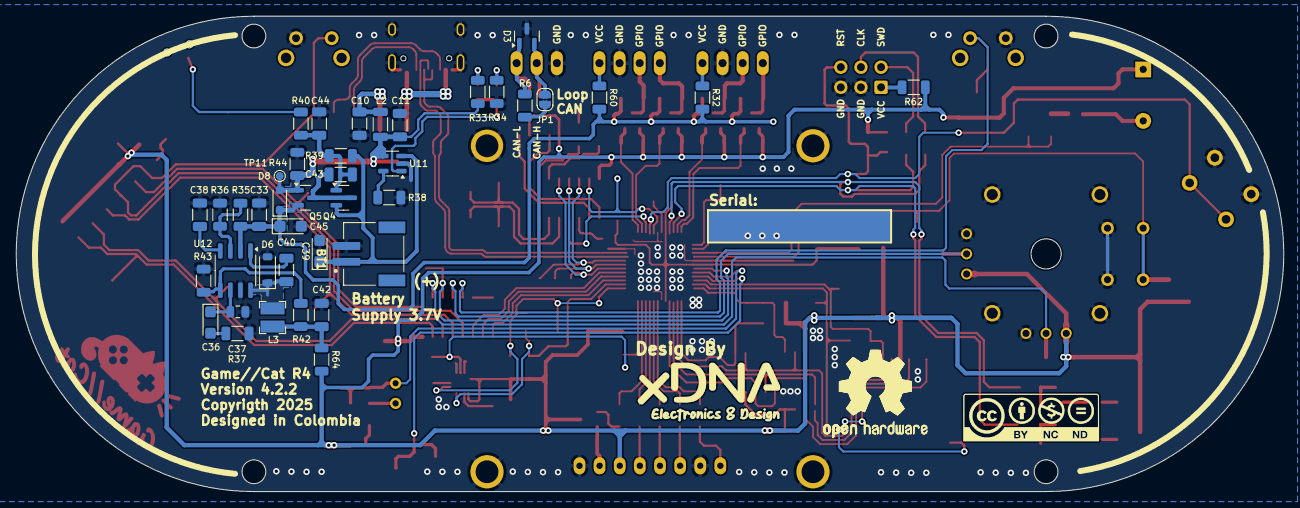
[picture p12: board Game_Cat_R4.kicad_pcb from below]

Board: 2 copper layers, 160.0 x 60.0 mm, 186 parts (40 on the bottom side), 113 nets.

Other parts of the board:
C43, C44: 100nF; C_1206_3216Metric

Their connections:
/POWER SUPPLY/BRG: C43.1; also elsewhere on the board
/POWER SUPPLY/M: C43.2, C44.1; also elsewhere on the board
GND: C44.2; also elsewhere on the board

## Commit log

2026-03-11 03/11/26/Update BOM & Models VRML
    [Game_Cat_R4-B_Cu.gbr, Game_Cat_R4-B_Mask.gbr, Game_Cat_R4-B_Paste.gbr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]
2026-03-11 03/12/26/Update BOM & Models VRML
    [Game_Cat_R4-B_Cu.gbr, Game_Cat_R4-B_Mask.gbr, Game_Cat_R4-B_Paste.gbr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]
